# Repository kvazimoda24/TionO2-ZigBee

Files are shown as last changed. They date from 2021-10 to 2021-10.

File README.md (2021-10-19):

## README.md
Проект для подключения бризера Tion O2 к умному дому через протокол ZigBee

Отлаживалось на бризерах выпущенных в октябре 2020 года. На экземплярах выпущенных раньше или позже может использоваться другой дисплей или другая прошивка.

В бризере в качестве контроллера ЖК дисплея используется микросхема HOLTEK HT1622.<br>
Основная идея заключается в том, что мы цепляемся паралельно входу этой микросхемы и снифим данные, отправляемые в неё.<br>
Для управления замыкаем выводы кнопок панели управления бризера имитируя, таким образом, нажатия на них.<br>

Ядром проекта является микроконтроллер **ATmega328P**.<br>
Для работы по протоколу ZigBee используется модуль **E18-MS1-PCB**. Так же пробовал модуль **E18-MS1PA1-PCB**, но из-за встроенного усилителя он слишком много потребляет, и его не вытягивает встроенный блок питания бризера.

### Статус
При изменениях температуры или режима работы бризера, а также примерно каждые 20 минут на координатор отправляется текущий статус бризера.<br>
Посылка представляет JSON вида: `{"PWR":"1","APW":"1","OUT":"5","SPD":"3","HTE":"1","TMS":"0","HTT":"18"}`<br>
Параметры:<br>
**PWR** - работает бризер или в режиме standbuy (0 - standbuy, 1 - работает)<br>
**APW** - включён ли режим автоматического включения после сбоя питания. Если 1, то после подачи питания, если на момент сбоя бризер был включён, то бризер включится.<br>
**OUT** - температура входящего воздуха<br>
**SPD** - скорость работы вентилятора (от 1 до 4)<br>
**HTE** - включён ли подогрев воздуха<br>
**HTT** - до какой температуры подогревается входящий воздух<br>
**FLT** - осталось дней до замены фильтров<br>
**MNT** - минимально допустимая температура входящего воздуха<br>
**TIM** - текущее время (формат ЧЧММ)<br>
**TMS** - включён ли таймер включения/выключения<br>
**TME** - время включения (формат ЧЧММ)<br>
**TMD** - время выключения (формат ЧЧММ)<br>
**ERROR** - в случае, если бризер отобразил ошибку, то будет отправлен только этот параметр, в значении будет строка с ошибкой. Так же, в случае, если не удалось распознать данные на дисплее, то в значении будет пусто.

### Управление
Для управления необходимо отправить строку, содержащую одну или несколько команд.<br>
Строка состоит из названия параметра, разделителя, значения параметра. Разделителем является двоеточие ":".<br>
Можно отправить разом несколько параметров. В этом случае параметры должны отделаться друг от друга запятой ","<br>
Оканчиваться строка должна символом возврата каретки (код символа 0x0D).<br>
Максимальная длинна строки 127 символов.<br>
Параметры будут применяться в том же порядке, что и в отправленной команде.<br>
Если встречается ошибочный параметр, то дальнейший разбор строки прекращается.<br>

Пример строки: `PWR:1,SPD:2,HTE:1,HTT:17\r`

Сами параметры аналогичны тем, что перечислены в статусе, за исключением параметра FLT - изменение срока замены фильтров я не реализовывал, т.к. не увидел необходимости в этом.<br>
Так же, добавлена дополнительная команда EXS. Значение можно выставить любое число до 4 знаков, например 1.<br>
При получении этой команды контроллер проходит по всем настройкам бризера и отправляет их координатору ZigBee сети. Это нужно, чтобы получить текущие значения таймеров, текущего времени, срока службы фильтров и минимально допустимой температуры.<br>

На стороне координатора я использую проект zigbee2mqtt. В нём статус можно получить по адресу *zigbee2mqtt/device_id/action*
Строка с командами же отправляется по адресу *zigbee2mqtt/device_id/set/action* содержимое `PWR:1,SPD:2,HTE:1,HTT:17`

### Каталоги и файлы
**arduino** - проект в Arduino IDE версии 1.8.16 - сдесь код для контроллера ATmega328P<br>
**kicad** - проект в kiCAD версии 5.0.2 - схема платы, печатная плата и готовые герберы.<br>
**CC2530** - прошивки для ZigBee модулей<br>
**TION-O2_ZIGBEE.js** - файл описания устройства для zigbee2mqtt. Его надо положить в каталог data проекта zigbee2mqtt и прописать в файле configuration.yaml:
```
external_converters:
  - TION-O2_ZIGBEE.js
```
Прошивка для ZigBee модуля создана с помощью контруктора прошивок с сайта https://ptvo.info<br>
Вдохновлялся проектом https://hackaday.io/project/168959-let-me-control-you-hitachi-air-conditioner<br>

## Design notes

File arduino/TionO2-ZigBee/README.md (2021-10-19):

FUSE BITS:<br>
EX: 0xFC<br>
HI: 0xDF<br>
LO: 0xD7

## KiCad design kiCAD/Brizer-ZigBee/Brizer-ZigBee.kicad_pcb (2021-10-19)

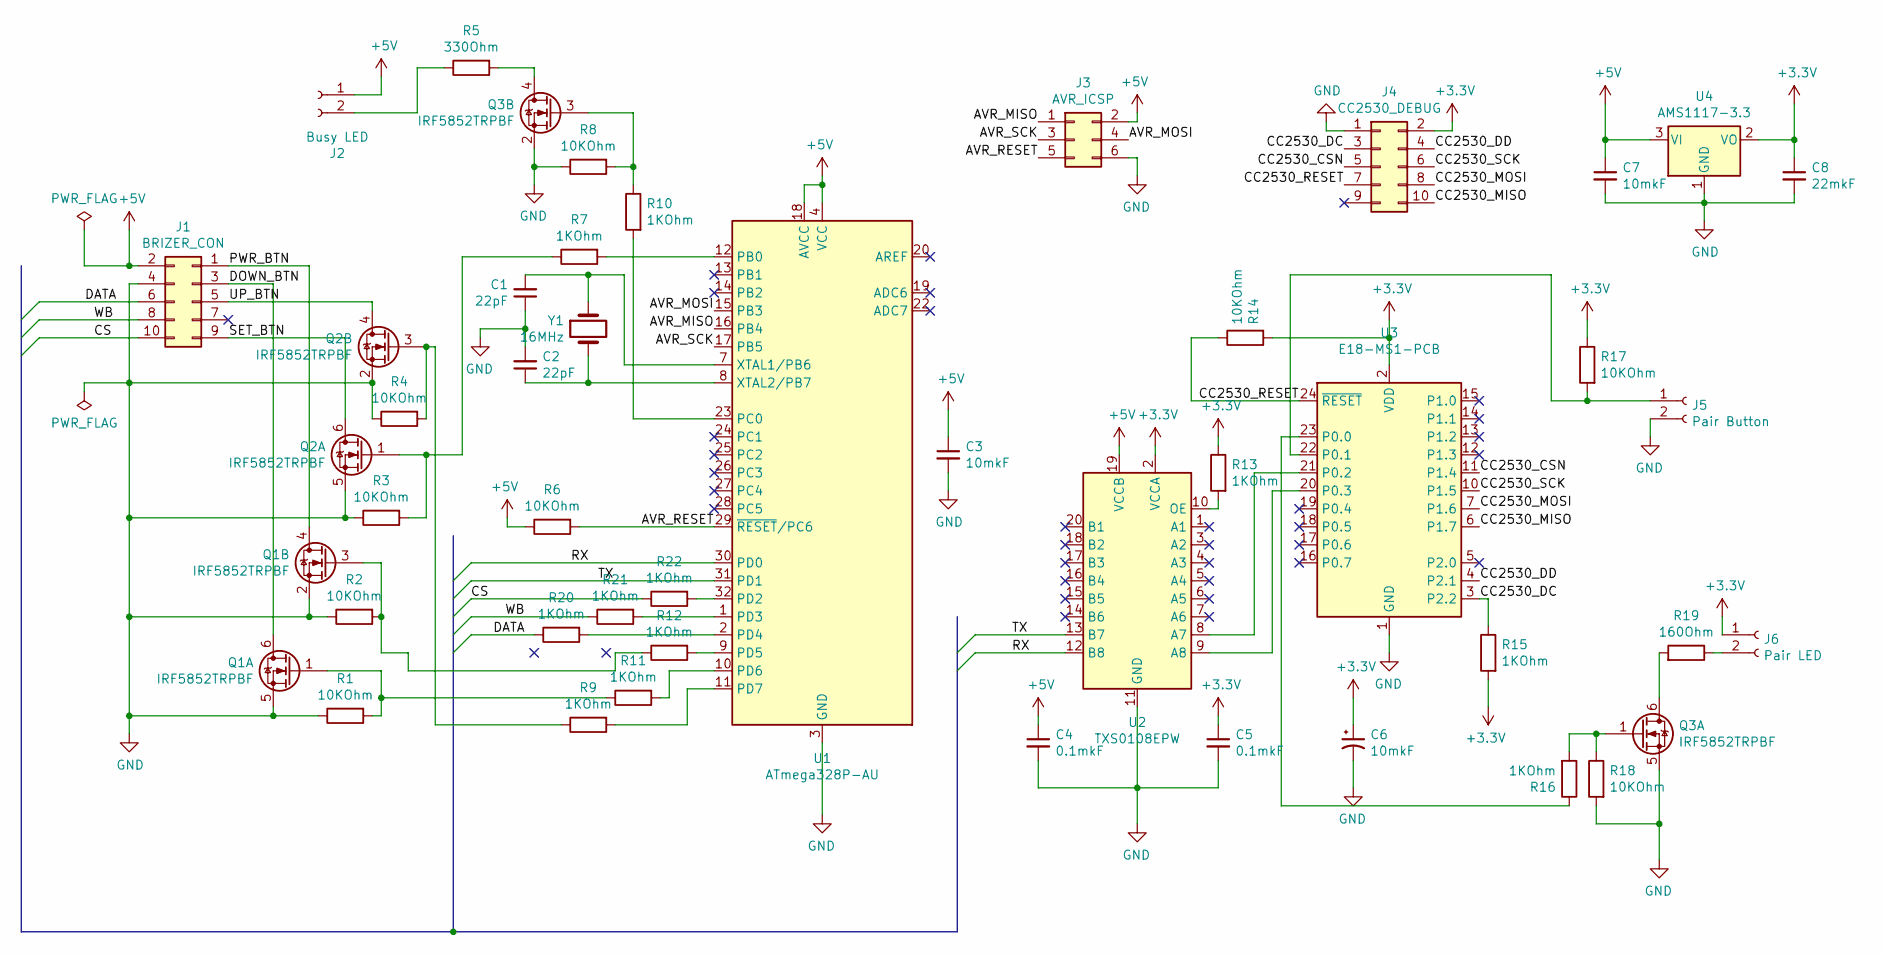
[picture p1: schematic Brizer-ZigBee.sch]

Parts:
C1, C2: 22pF; C_0805_2012Metric
C3, C7: 10mkF; C_0805_2012Metric
C4, C5: 0.1mkF; C_1206_3216Metric
C6: 10mkF; CP_EIA-3528-21_Kemet-B
C8: 22mkF; C_0805_2012Metric
J1: BRIZER_CON; IDC-Header_2x05_P2mm_Vertical
J2: Busy LED; PinHeader_1x02_P2.54mm_Vertical
J3: AVR_ICSP; PinHeader_2x03_P2.00mm_Vertical
J4: CC2530_DEBUG; PinHeader_2x05_P2.00mm_Vertical
J5: Pair Button; PinHeader_1x02_P2.54mm_Vertical
J6: Pair LED; PinHeader_1x02_P2.54mm_Vertical
Q1, Q2, Q3: IRF5852TRPBF; TSOP-6_1.65x3.05mm_P0.95mm
R1, R2, R3, R4, R6, R8, R14, R17, R18: 10KOhm; R_0805_2012Metric
R5: 330Ohm; R_0805_2012Metric
R7, R9, R10, R11, R12, R13, R15, R16, R20, R21, R22: 1KOhm; R_0805_2012Metric
R19: 160Ohm; R_0805_2012Metric
U1: ATmega328P-AU; TQFP-32_7x7mm_P0.8mm
U2: TXS0108EPW; TSSOP-20_4.4x6.5mm_P0.65mm
U3: E18-MS1-PCB; E18-MS1PA1-PCB
U4: AMS1117-3.3; SOT-223-3_TabPin2
Y1: 16MHz; Crystal_SMD_HC49-SD

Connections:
+3V3: C5.1, C6.1, C8.1, J4.2, J6.1, R13.1, R14.2, R15.2, R17.1, U2.2 (VCCA), U3.2 (VDD), U4.2 (VO)
+5V: C3.1, C4.1, C7.1, J1.2, J2.1, J3.2, R6.1, U1.4 (VCC), U1.6 (VCC), U1.18 (AVCC), U2.19 (VCCB), U4.3 (VI)
/AVR_MISO: J3.1, U1.16 (PB4)
/AVR_MOSI: J3.4, U1.15 (PB3)
/AVR_RESET: J3.5, R6.2, U1.29 (~RESET~/PC6)
/AVR_SCK: J3.3, U1.17 (PB5)
/CC2530_CSN: J4.5, U3.11 (P1.4)
/CC2530_DC: J4.3, R15.1, U3.3 (P2.2)
/CC2530_DD: J4.4, U3.4 (P2.1)
/CC2530_MISO: J4.10, U3.6 (P1.7)
/CC2530_MOSI: J4.8, U3.7 (P1.6)
/CC2530_RESET: J4.7, R14.1, U3.24 (~RESET)
/CC2530_SCK: J4.6, U3.10 (P1.5)
/CS: J1.10, R22.1
/DATA: J1.6, R20.1
/DOWN_BTN: J1.3, Q1.6 (D)
/PWR_BTN: J1.1, Q1.4 (D)
/RX: U1.30 (PD0), U2.12 (B8)
/SET_BTN: J1.9, Q2.6 (D)
/TX: U1.31 (PD1), U2.13 (B7)
/UP_BTN: J1.5, Q2.4 (D)
/WB: J1.8, R21.1
GND: C1.1, C2.2, C3.2, C4.2, C5.2, C6.2, C7.2, C8.2, J1.4, J3.6, J4.1, J5.2, Q1.2 (S), Q1.5 (S), Q2.2 (S), Q2.5 (S), Q3.2 (S), Q3.5 (S), R1.1, R2.1, R3.1, R4.1, R8.1, R18.2, U1.3 (GND), U1.5 (GND), U1.21 (GND), U2.11 (GND), U3.1 (GND), U4.1 (GND)
unnamed: C1.2, U1.7 (XTAL1/PB6), Y1.1
unnamed: C2.1, U1.8 (XTAL2/PB7), Y1.2
unnamed: J2.2, R5.1
unnamed: J5.1, R17.2, U3.22 (P0.1)
unnamed: J6.2, R19.1
unnamed: Q1.1 (G), R1.2, R11.1
unnamed: Q1.3 (G), R2.2, R12.1
unnamed: Q2.1 (G), R3.2, R7.1
unnamed: Q2.3 (G), R4.2, R9.1
unnamed: Q3.1 (G), R16.2, R18.1
unnamed: Q3.3 (G), R8.2, R10.1
unnamed: Q3.4 (D), R5.2
unnamed: Q3.6 (D), R19.2
unnamed: R7.2, U1.12 (PB0)
unnamed: R9.2, U1.11 (PD7)
unnamed: R10.2, U1.23 (PC0)
unnamed: R11.2, U1.10 (PD6)
unnamed: R12.2, U1.9 (PD5)
unnamed: R13.2, U2.10 (OE)
unnamed: R16.1, U3.23 (P0.0)
unnamed: R20.2, U1.2 (PD4)
unnamed: R21.2, U1.1 (PD3)
unnamed: R22.2, U1.32 (PD2)
unnamed: U2.8 (A7), U3.21 (P0.2)
unnamed: U2.9 (A8), U3.20 (P0.3)

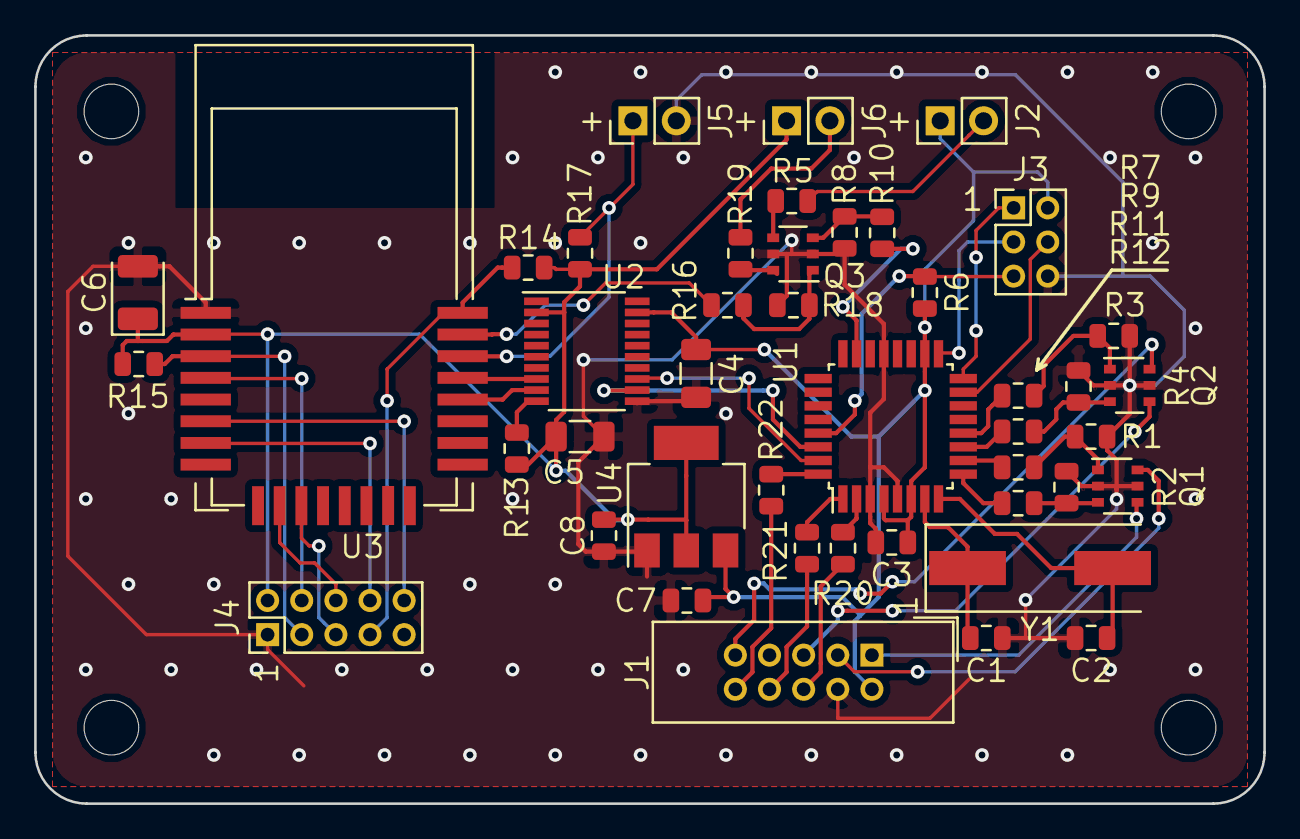
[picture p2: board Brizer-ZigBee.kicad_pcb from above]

Board: 2 copper layers, 72.0 x 45.0 mm, 44 parts (0 on the bottom side), 48 nets.

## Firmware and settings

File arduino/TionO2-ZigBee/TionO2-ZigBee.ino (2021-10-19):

#include <avr/eeprom.h>

//INT0 - WD
//INT1 - RD
//PCINT2 - CS

#define READBUFFERSIZE 64
#define LCDSIZE 12
#define LCDBLINKTIME 450 //  step 16,384ms
#define STARTREADTIMEOUT 225
#define FREQUENCYSENDSTATE 2400 // step 0.5 seconds

#define SHORTPRESS 100
#define LONGPRESS 2200
#define DELAYPRESS 100

#define SERIAL_TX_BUFFER_SIZE 128
#define SERIAL_RX_BUFFER_SIZE 128
#define OUTPUT_SERIAL_BUFFER 100

#define EEPROMAUTOSTART 0

uint8_t SerialCmd[4];

char OutputSerialBuffer[OUTPUT_SERIAL_BUFFER];

volatile uint8_t Active = 0;
volatile uint8_t NewData = 0;

volatile uint8_t ReadBuffer[READBUFFERSIZE];
volatile uint8_t ReadBufferPointer = 0;
volatile uint8_t ReadBitPointer = 0;
volatile uint8_t ReadPause = 0;
volatile uint8_t Input;

volatile uint8_t StartRead = 0;
volatile uint8_t ReadTimer = 0;
volatile uint8_t ErrorRead = 0;
uint8_t LCDState[LCDSIZE];
uint8_t LCDState2[LCDSIZE];

uint8_t BrizerAutoStart, BrizerPower, BrizerSpeed, BrizerHeatStateSetting, BrizerHeatState;
int8_t  BrizerOutsideTemp, BrizerHeatTemp, BrizerMinOutTemp;
int16_t BrizerFilterTime;
uint8_t BrizerTimerState, BrizerTimerOnHR, BrizerTimerOnMIN;
uint8_t BrizerTimerOffHR, BrizerTimerOffMIN;
uint8_t BrizerTimeHR, BrizerTimeMIN;
char BrizerErrorStr[5];

uint8_t FlagChangeValues;
uint16_t Cicles;

#define CHARARRAYSIZE 22
const PROGMEM uint8_t CharArray[] = {
  0x77, 0x12, 0x6B, 0x5B, 0x1E, 0x5D, 0x7D, 0x13, 0x7F, 0x5F,  // 0-9
  0x3F, 0x7C, 0x65, 0x7A, 0x6D, 0x2D,                          // A-F
  0x38, 0x78, 0x28, 0x08, 0x00, 0x37                           // n, o, r, -, space, N
};
const PROGMEM uint8_t Char2CharArray[] = {
  0x30, 0x31, 0x32, 0x33, 0x34, 0x35, 0x36, 0x37, 0x38, 0x39,  // 0-9
  0x41, 0x42, 0x43, 0x44, 0x45, 0x46,                          // A-F
  0x6E, 0x6F, 0x72, 0x2D, 0x20, 0x4E                           // n, o, r, -, space, N
};

void setup() {
  // PORD 2-4 INPUT
  DDRD &= ~(B00011100);
  //PORTD 5-7 OUTPUT and DOWN
  DDRD |= B11100000;
  PORTD &= ~(B11100000);
  // PORTB 0 OUTPUT and DOWN
  DDRB |= B1;
  PORTB &= ~(B1);
  // PORTC 0 OUTPUT and DOWN
  DDRC |= B1;
  PORTC &= ~(B1);

  // Serial
  Serial.begin(9600);
  //Serial.println("Start");

  setupInterupts();
  autoStart();
  sendExtStatus();
}

void loop() {
  Serial.flush();
  checkSerialRX();
  uint8_t Screen = analyseLCD();
  savePowerState();
  if (Cicles > FREQUENCYSENDSTATE) FlagChangeValues = 1;
  sendState(Screen);
  Cicles++;
  delay(500);
}

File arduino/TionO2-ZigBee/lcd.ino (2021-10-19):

void interuptSet(uint8_t Cmd) {
  // Save state and disable/restore interupts
  // Cmd 1 - save and disable
  // Cmd 0 - restore
  
  static uint8_t SavePCICR;
  static uint8_t SaveTIMSK0;
  static uint8_t SaveSPCR;
  if(Cmd) {
    SavePCICR = PCICR;
    SaveTIMSK0 = TIMSK0;
    SaveSPCR = SPCR>>7;
    
    PCICR = 0;
    TIMSK0 = 0;
    SPCR &= ~(B10000000);
    return;
  }
  PCICR = SavePCICR;
  TIMSK0 = SaveTIMSK0;
  SPCR |= SaveSPCR<<7;
}

uint8_t getDump(uint8_t *State) {
  uint8_t i, p;
  uint16_t serBuf; 
  for (i=0; i<READBUFFERSIZE; i++) {
    ReadBuffer[i] = 0;
  }
  StartRead = 1;
  ReadBitPointer = 0;
  ReadBufferPointer = 0;
  ReadTimer = 0;
  Active = 1;
  serBuf = Serial.available();
  interuptSet(1);  // Save and disable other interupt
  
  PORTC |= B00000001;
  TCNT2 = STARTREADTIMEOUT;
  EIFR = B00000001;
  TIFR2 = B00000001;
  EIMSK = B00000001;  // Enable INT0
  TIMSK2 = 1;
  while (Active == 1) ;
  interuptSet(0);  // Enable other interupts
  
  serBuf = Serial.available() - serBuf;
  if (NewData == 0 || ErrorRead == 1 || serBuf != 0) {
    for (i=0; i<LCDSIZE; i++) {
      State[i] = 0;
    }
    return 1;
  }
  i = 0;
  p = 1;
  while (i < LCDSIZE && p < READBUFFERSIZE) {
    State[i] = ReadBuffer[p]<<1;
    State[i] |= ReadBuffer[p+1]&B00000001;
    i++;
    p = p + 3;
  }
  return 0;
}

uint8_t readLCD() {
  uint8_t i;
  for (i=0; i < 8; i++) {
    if (getDump(LCDState)) continue;
    delay(LCDBLINKTIME);
    if (getDump(LCDState2)) continue;
    break;
  }
  
  if (i >= 8) return 1;
  for (i=0; i<LCDSIZE; i++) {
    LCDState[i] |= LCDState2[i];
  }
  return 0;
}

uint8_t smallDigit2BigDigit(uint8_t LByte, uint8_t HByte) {
  uint8_t BigDg;
  BigDg = (HByte&B00010000)<<2;
  BigDg |= (LByte&B00001000)<<2;
  BigDg |= (HByte&B00001000)<<1;
  BigDg |= (LByte&B00000110)<<1;
  BigDg |= (HByte&B00000110)>>1;
  return BigDg;
}

uint8_t segments2Digit(uint8_t InByte) {
  InByte &= ~(B10000000);
  uint8_t Return = 0xFF;
  uint8_t i;
  for (i=0; i<CHARARRAYSIZE; i++) {
    if (InByte == pgm_read_byte_near(&CharArray[i])) {
      Return = i;
      break;
    }
  }
  return Return;
}

int8_t decode2Digits(uint8_t HByte, uint8_t LByte) {
  int8_t Return;
  uint8_t HDigit = segments2Digit(HByte);
  if (HDigit > 9) {
    if (HDigit != 19 && HDigit != 20) return 127;
    Return = 0;
  } else Return = HDigit;
  
  uint8_t LDigit = segments2Digit(LByte);
  if (LDigit <= 9) {
    Return *= 10;
    Return += LDigit;
  }
  if (HDigit == 20 && LDigit == 20) return 127;
  if (HByte&B10000000 || HDigit == 19) Return *= -1;
  return Return;
}

uint16_t decode3Digits(uint8_t HByte, uint8_t MByte, uint8_t LByte) {
  uint16_t Return = segments2Digit(HByte) * 100;
  Return += segments2Digit(MByte) * 10;
  Return += segments2Digit(LByte);
  return Return;
}

uint8_t getSpeed() {
  if (LCDState[3]&B00001100) return 4;
  if (LCDState[3]&B00010000) return 3;
  if (LCDState[2]&B00010000) return 2;
  if (LCDState[2]&B00000110) return 1;
  return 0;
}

uint8_t getScreen() {
  uint8_t Byte0 = segments2Digit(LCDState[0]);
  if (Byte0 == 21) return 0;                   // One of the error screens 
  
  if (LCDState[2]&B1100) return 1;             // Main screen

  if (Byte0 == 19) return 2;                  // Off screen

  if (LCDState[3]&1) return 4;                // Set time

  if (LCDState[2]&B10) return 6;              // Set start timer screen

  if (LCDState[3]&B10) return 7;              // Set stop timer screen

  if (LCDState[8]&B10000) return 5;           // Set on/off timer screen

  if (LCDState[4] && !LCDState[0]) return 3;  // Set temperature screen

  if (LCDState[0] && !LCDState[4]) return 8;  // Set min outside temperature

  if (LCDState[6]&1) return 9;                // Set filter timer screen

  return 0;                                   // Error screen
}

void mainScr() {
  int8_t T;
  if (BrizerPower == 0) FlagChangeValues = 1;
  BrizerPower = 1;
  T = getSpeed();
  if (BrizerSpeed != T) FlagChangeValues = 1;
  BrizerSpeed = T;
  heatScr();
  T = decode2Digits(LCDState[0], LCDState[1]);
  if (BrizerOutsideTemp != T) FlagChangeValues = 1;
  BrizerOutsideTemp = T;
  T = (LCDState[8]>>4)&1;
  if (BrizerTimerState != T) FlagChangeValues = 1;
  BrizerTimerState = T;
  if (LCDState[6]&1) filterScr();
}

void heatScr() {
  int8_t T;
  if (BrizerPower == 0) FlagChangeValues = 1;
  BrizerPower = 1;
  T = (~(LCDState[3]>>5)&1);
  if (BrizerHeatStateSetting != T) FlagChangeValues = 1;
  BrizerHeatStateSetting = T;
  int8_t HeatTemp = decode2Digits(LCDState[4], LCDState[5]);
  if (HeatTemp > 100) {
    if (BrizerHeatState != 0) FlagChangeValues = 1;
    BrizerHeatState = 0;
  } else {
    if (BrizerHeatState != 1) FlagChangeValues = 1;
    BrizerHeatState = 1;
    if (BrizerHeatTemp != HeatTemp) FlagChangeValues = 1;
    BrizerHeatTemp = HeatTemp;
  }
}

void filterScr() {
  if (BrizerPower == 0) FlagChangeValues = 1;
  BrizerPower = 1;
  uint16_t T;
  uint8_t HByte, MByte, LByte;
  HByte = smallDigit2BigDigit(LCDState[6], LCDState[7]);
  MByte = smallDigit2BigDigit(LCDState[8], LCDState[9]);
  LByte = smallDigit2BigDigit(LCDState[10], LCDState[11]);
  T= decode3Digits(HByte, MByte, LByte);
  if (BrizerFilterTime != T) FlagChangeValues = 1;
  BrizerFilterTime = T;
}

void timeScr(uint8_t Screen) {
  BrizerPower = 1;
  uint8_t Hours, Minutes;
  Hours = decode2Digits(LCDState[0], LCDState[1]);
  Minutes = decode2Digits(LCDState[4], LCDState[5]);
  switch (Screen) {
    case 4:
      BrizerTimeHR = Hours;
      BrizerTimeMIN = Minutes;
      break;
    case 6:
      BrizerTimerOnHR = Hours;
      BrizerTimerOnMIN = Minutes;
      break;
    case 7:
      BrizerTimerOffHR = Hours;
      BrizerTimerOffMIN = Minutes;
      break;
  }
}

void timerStScr() {
  BrizerPower = 1;
  uint8_t Char2 = smallDigit2BigDigit(LCDState[8], LCDState[9]);
  if (Char2 == 0x38) BrizerTimerState = 1;
  else BrizerTimerState = 0;
}

void minOutTempScr() {
  BrizerPower = 1;
  BrizerMinOutTemp = decode2Digits(LCDState[0], LCDState[1]);
}

void offScr() {
  if (BrizerPower == 1) FlagChangeValues = 1;
  BrizerPower = 0;
  BrizerTimerState = (LCDState[8]>>4)&1;
}

void errorScr() {
  if (FlagChangeValues < 2) FlagChangeValues = 1;
  BrizerErrorStr[0] = pgm_read_byte_near(&Char2CharArray[segments2Digit(LCDState[0])]);
  BrizerErrorStr[1] = pgm_read_byte_near(&Char2CharArray[segments2Digit(LCDState[1])]);
  if (BrizerErrorStr[0] == 0x4E && BrizerErrorStr[1] == 0x30 ) BrizerErrorStr[1] = 0x4F;
  BrizerErrorStr[2] = pgm_read_byte_near(&Char2CharArray[segments2Digit(LCDState[4])]);
  BrizerErrorStr[3] = pgm_read_byte_near(&Char2CharArray[segments2Digit(LCDState[5])]);
  BrizerErrorStr[4] = '\0';
}
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

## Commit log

2021-10-19 Load project
    [Brizer-ZigBee-B.Cu.gbr, Brizer-ZigBee-B.Mask.gbr, Brizer-ZigBee-B.SilkS.gbr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]
2021-10-19 Add README with Fuse bits for ATmega
